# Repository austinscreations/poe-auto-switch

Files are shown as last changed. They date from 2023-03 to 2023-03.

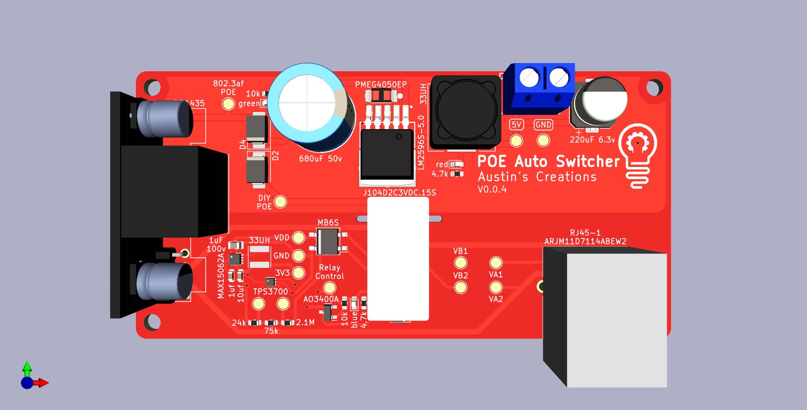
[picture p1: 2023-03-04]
images/POE auto switch 004 top.jpg

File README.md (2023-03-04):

# poe-auto-switch
a circuit designed to handle all 3 forms of poe and auto switch between them as required

802.3af POE aka auto negotated with a network switch (pins 1/2 &3/6) 
802.3af Passive POE (pins 4/5 & 7/8)
DIY POE (pins 4/5 & 7/8)

see it in action on youtube: 

https://www.youtube.com/watch?v=DrwicD6_NDw

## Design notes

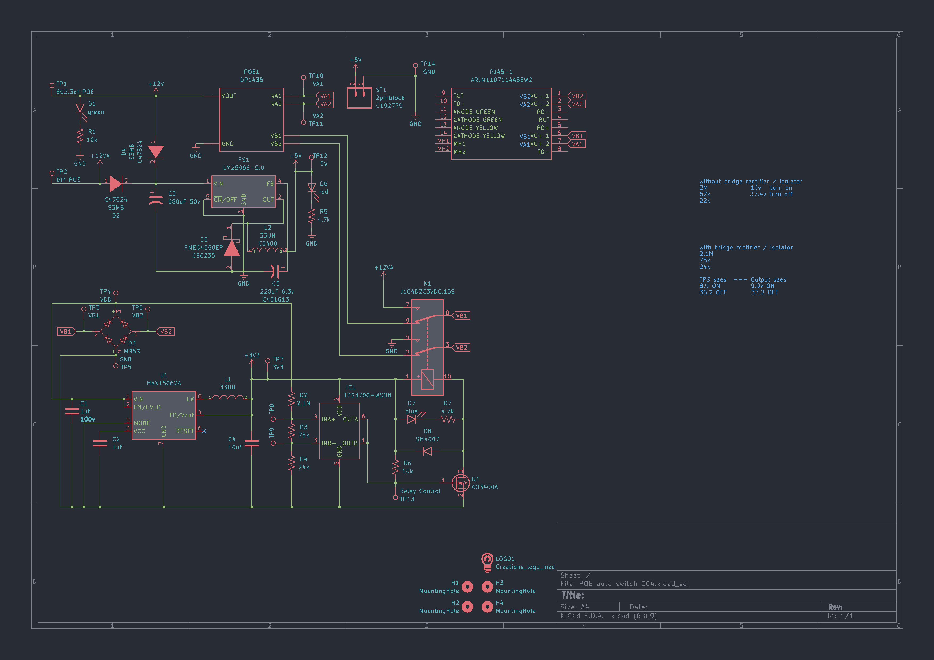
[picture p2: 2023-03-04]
images/POE auto switch 004 schematic.png

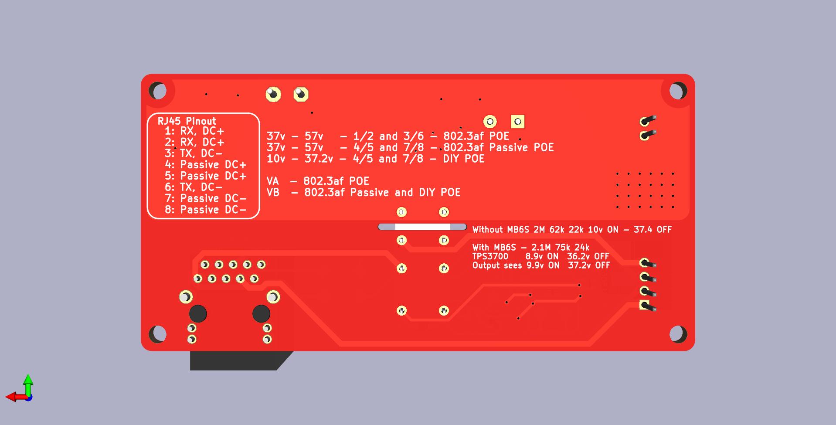
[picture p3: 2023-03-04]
images/POE auto switch 004 bottom.jpg

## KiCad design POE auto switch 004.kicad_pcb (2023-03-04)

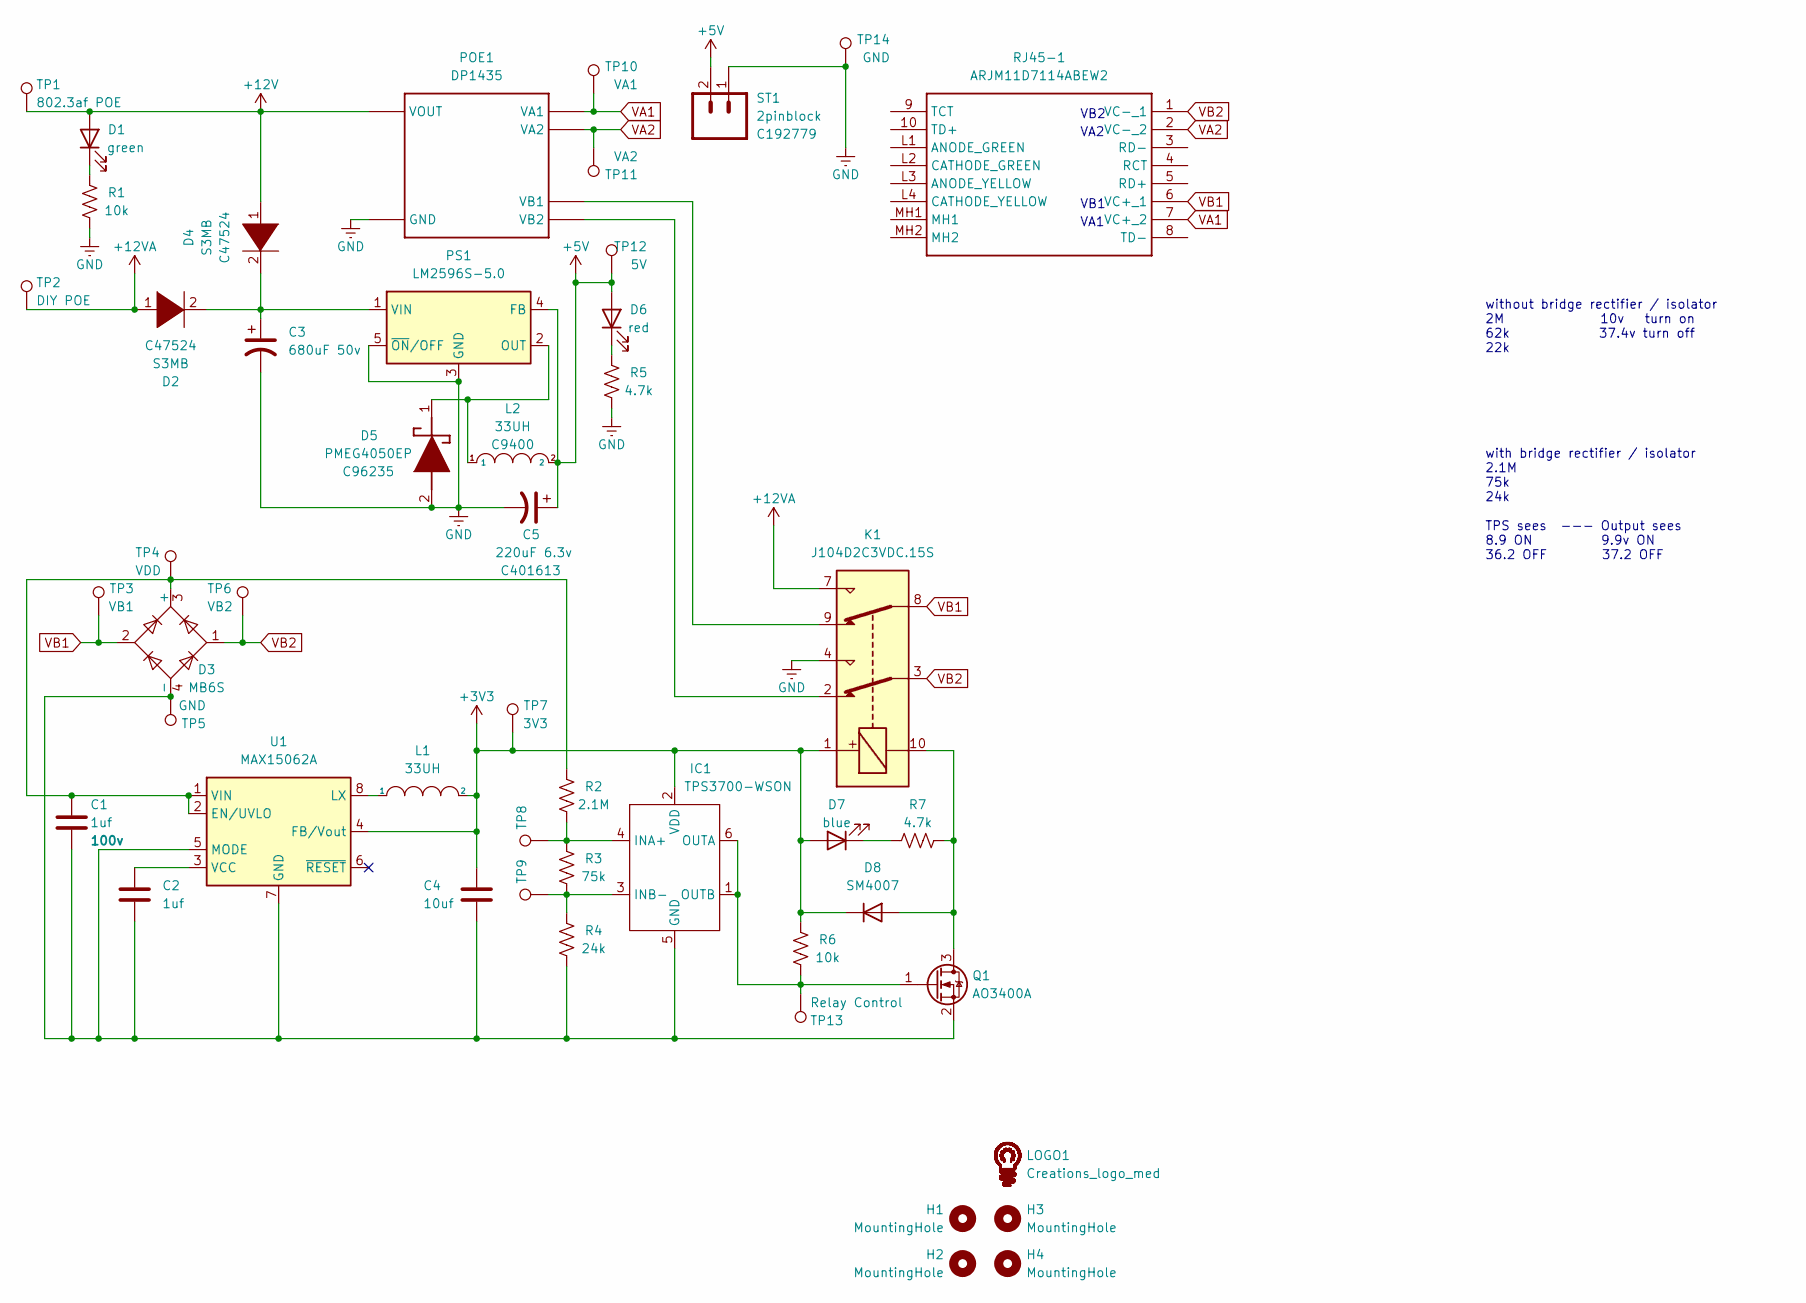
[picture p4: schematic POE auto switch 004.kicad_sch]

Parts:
C1: 1uf; C_0805_2012Metric; voltage 100v
C2: 1uf; C_0603_1608Metric
C3: 680uF 50v; CP_Radial_D13.0mm_P5.00mm
C4: 10uf; C_0603_1608Metric
C5: 220uF 6.3v; CP_Elec_8x6.2; part # C401613
D1: green; LED_0603_1608Metric
D2, D4: S3MB; D_SMB; part # C47524
D3: MB6S; TO-269AA
D5: PMEG4050EP; PMEG3050EP; part # C96235
D6: red; LED_0603_1608Metric
D7: blue; LED_0603_1608Metric
D8: SM4007; D_SOD-123F
H1, H2, H3, H4: MountingHole; MountingHole_3.2mm_M3
IC1: TPS3700-WSON; WSON-6_1.5x1.5mm_P0.5mm
K1: J104D2C3VDC.15S; Relay_DPDT_Finder_30.22
L1: 33UH; L_Vishay_IFSC-1515AH_4x4x1.8mm
L2: 33UH; 12x12x8 inductor; part # C9400
LOGO1: Creations_logo_med; Creations logo med
POE1: DP1435
PS1: LM2596S-5.0; LM2596S
Q1: AO3400A; SOT-23
R1, R6: 10k; R_0603_1608Metric
R2: 2.1M; R_0603_1608Metric
R3: 75k; R_0603_1608Metric
R4: 24k; R_0603_1608Metric
R5, R7: 4.7k; R_0603_1608Metric
RJ45-1: ARJM11D7114ABEW2
ST1: 2pinblock; part # C192779
TP1: 802.3af POE; TestPoint_Pad_D2.0mm
TP2: DIY POE; TestPoint_Pad_D2.0mm
TP3: VB1; TestPoint_Pad_D2.0mm
TP4: VDD; TestPoint_Pad_D2.0mm
TP5, TP14: GND; TestPoint_Pad_D2.0mm
TP6: VB2; TestPoint_Pad_D2.0mm
TP7: 3V3; TestPoint_Pad_D2.0mm
TP8, TP9: testpoint; TestPoint_Pad_D2.0mm
TP10: VA1; TestPoint_Pad_D2.0mm
TP11: VA2; TestPoint_Pad_D2.0mm
TP12: 5V; TestPoint_Pad_D2.0mm
TP13: Relay Control; TestPoint_Pad_D2.0mm
U1: MAX15062A; DFN-8_2x2mm_P0.5mm

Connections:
+3V3: C4.1, D7.2 (A), D8.1 (K), IC1.2 (VDD), K1.1, L1.2, R6.1, TP7.1, U1.4 (FB/Vout)
+5V: C5.1, D6.2 (A), L2.2, PS1.4 (FB), ST1.2, TP12.1
+12V: D1.2 (A), D4.1 (K), POE1.VOUT, TP1.1
+12VA: D2.1 (K), K1.7, TP2.1
GNDREF: C3.2, C5.2, D5.2 (A), K1.4, POE1.GND, PS1.3 (GND), PS1.5 (~ON/OFF), R1.2, R5.2, ST1.1, TP14.1
unnamed: C1.1, D3.3 (+), R2.1, TP4.1, U1.1 (VIN), U1.2 (EN/UVLO)
unnamed: C1.2, C2.2, C4.2, D3.4 (-), IC1.5 (GND), Q1.2 (S), R4.2, TP5.1, U1.5 (MODE), U1.7 (GND)
unnamed: C2.1, U1.3 (VCC)
unnamed: C3.1, D2.2 (A), D4.2 (A), PS1.1 (VIN)
unnamed: D1.1 (K), R1.1
unnamed: D5.1 (K), L2.1, PS1.2 (OUT)
unnamed: D6.1 (K), R5.1
unnamed: D7.1 (K), R7.1
unnamed: D8.2 (A), K1.10, Q1.3 (D), R7.2
unnamed: IC1.1 (OUTB), IC1.6 (OUTA), Q1.1 (G), R6.2, TP13.1
unnamed: IC1.3 (INB-), R3.2, R4.1, TP9.1
unnamed: IC1.4 (INA+), R2.2, R3.1, TP8.1
unnamed: K1.2, POE1.VB2
unnamed: K1.9, POE1.VB1
unnamed: L1.1, U1.8 (LX)
VA1: POE1.VA1, RJ45-1.7 (VC+_2), TP10.1
VA2: POE1.VA2, RJ45-1.2 (VC-_2), TP11.1
VB1: D3.2, K1.8, RJ45-1.6 (VC+_1), TP3.1
VB2: D3.1, K1.3, RJ45-1.1 (VC-_1), TP6.1

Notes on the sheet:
with bridge rectifier / isolator 2.1M 75k 24k TPS sees --- Output sees 8.9 ON 9.9v ON 36.2 OFF 37.2 OFF
without bridge rectifier / isolator 2M 10v turn on 62k 37.4v turn off 22k
VA1
VA2
VB2
VB1

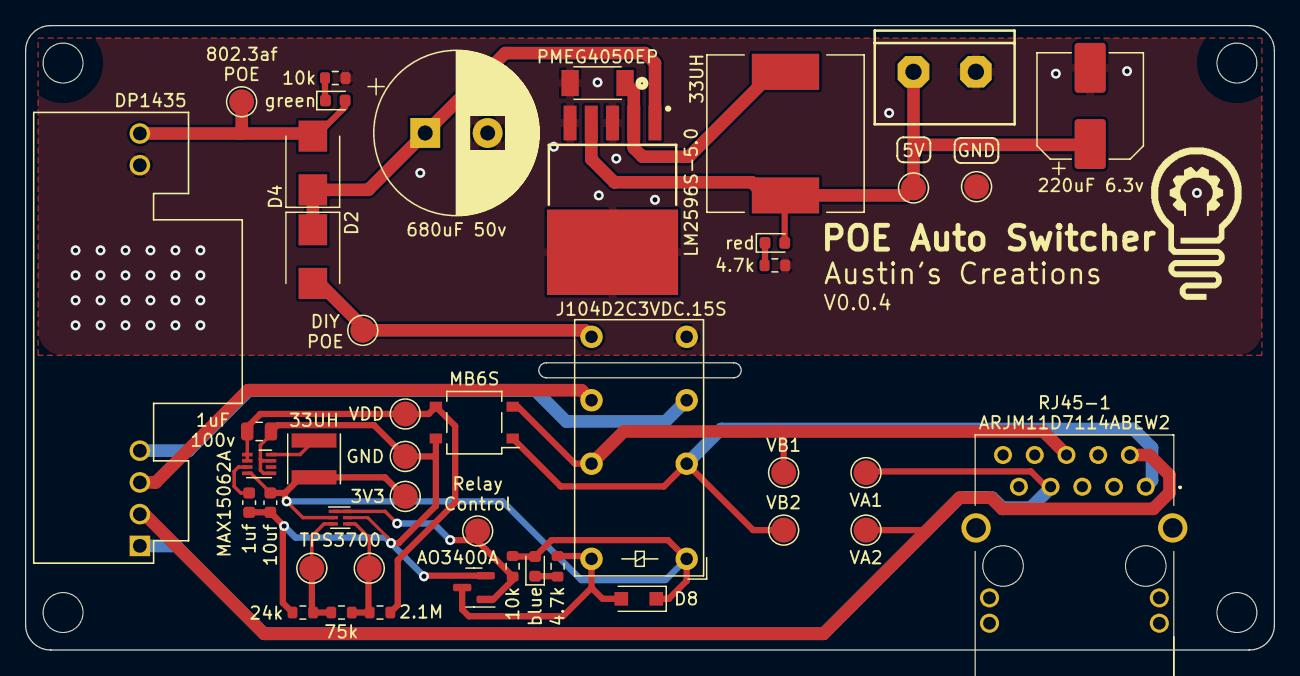
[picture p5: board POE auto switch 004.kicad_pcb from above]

Board: 2 copper layers, 100.0 x 50.0 mm, 49 parts (0 on the bottom side), 24 nets.
